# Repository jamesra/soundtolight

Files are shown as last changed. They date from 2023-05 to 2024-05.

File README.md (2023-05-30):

# Sound To Light

## Introduction

Sound to Light (aka Sound Delight) is a audio spectrogram display for Adafruit Feathers.  Among other uses it is a fun visual accompaniment to music.  

## Project Materials

### Hardware

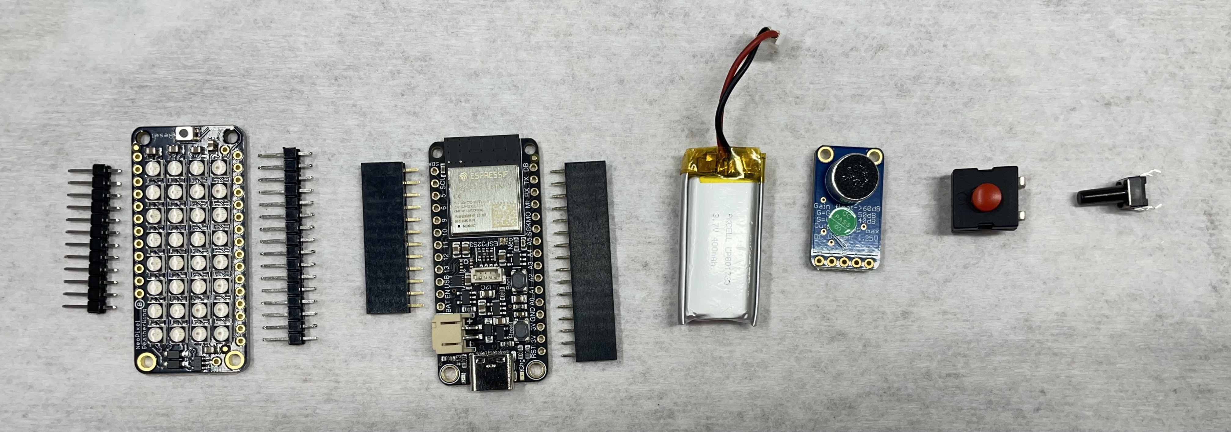
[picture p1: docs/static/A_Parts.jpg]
Parts


Displayed from left to right in the image above

- [Male Headers](https://www.adafruit.com/product/2886)
- [NeoPixel FeatherWing](https://www.adafruit.com/product/2945)
- [Female Headers](https://www.adafruit.com/product/2940)
- [ESP32-S3 board with 2MB PSRAM](https://www.adafruit.com/product/5477).
- *Optional* [Battery](https://www.adafruit.com/product/3898)
- [Electret Microphone with Auto Gain Control](https://www.adafruit.com/product/1713)
- 0.5m of any workable gauge [wire](https://www.adafruit.com/product/2515)
- *Optional* [On/Off Switch](https://www.adafruit.com/product/1683)
- *Optional* [Mode Button](https://www.adafruit.com/product/1490)

The case is 3D printed.  If you do not own a 3D printer many towns have a local 3D printing business.  If not there are online services that will mail a print.

### Tools:
    
- Soldering Iron
- Wire strippers

### Helpful Tools:

- Helping Hands
- Breadboard
- Flush Cutters
- Board Holder

## Instructions

### 1. Solder on the male headers onto the NeoPixel Featherwing display.  

The easiest way is insert the male headers into the breadboard with the long pins down so the featherwing can rest on top. 

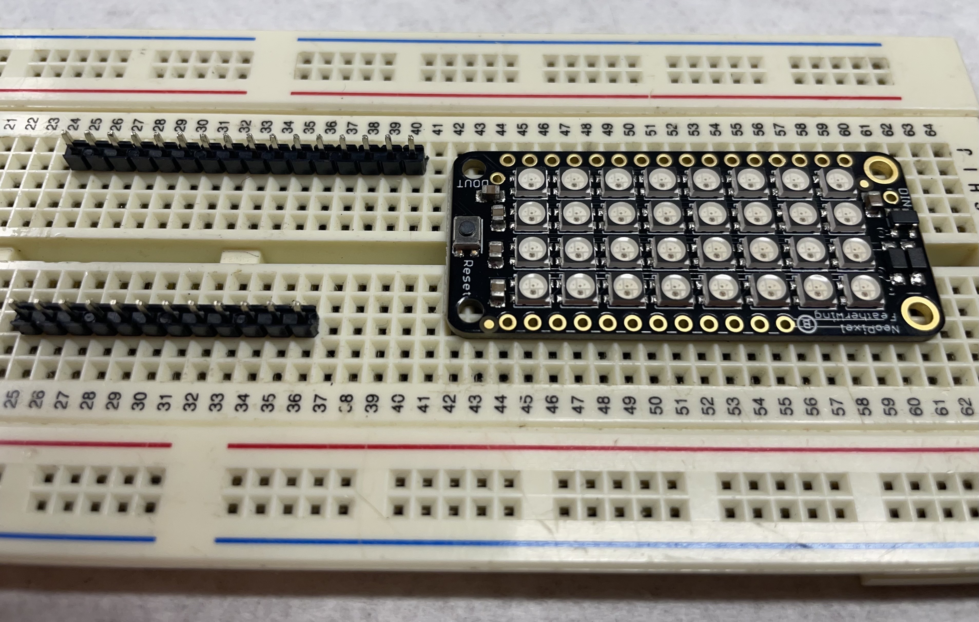
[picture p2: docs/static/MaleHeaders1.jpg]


Place the featherwing on top of the male headers. 

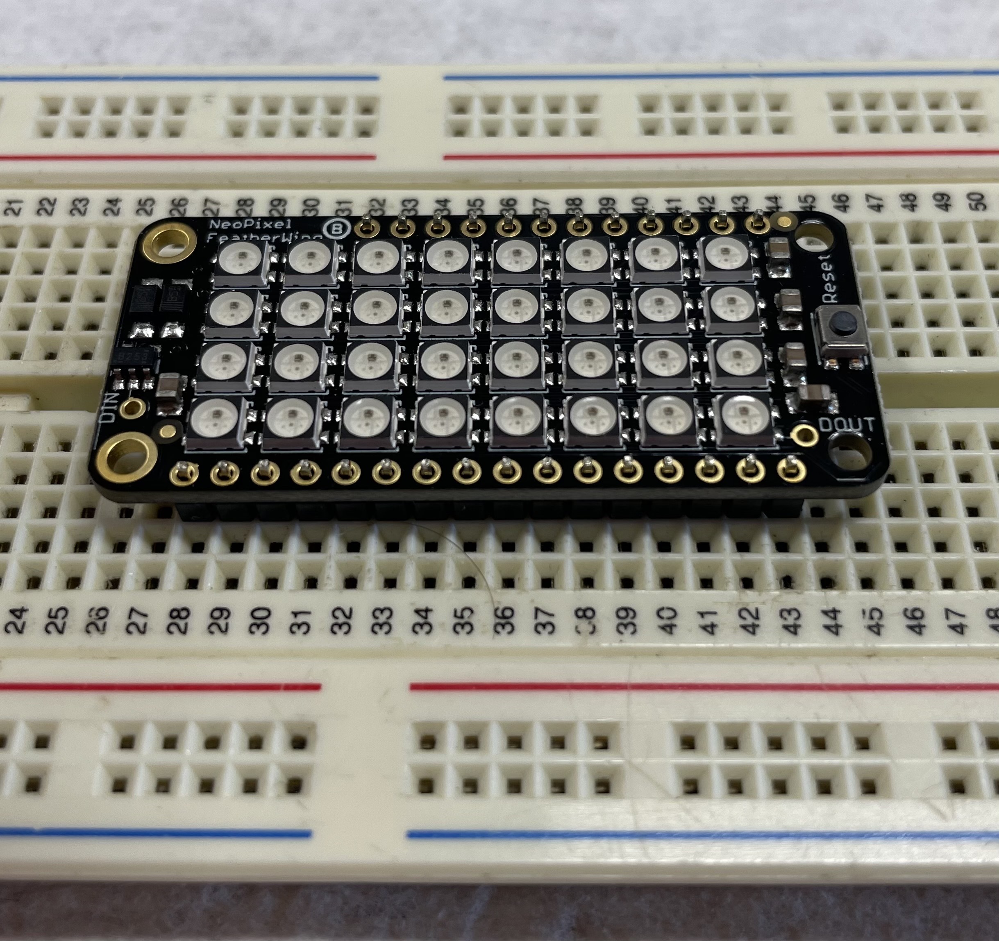
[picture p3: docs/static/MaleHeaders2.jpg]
 

*Note: If you do not have a breadboard, complete soldering the female headers to the ESP32-S3 from the step below, then place your male headers in the female headers to get the correct placement*

Solder each pin.  **Be very careful to not touch the NeoPixels with the iron as LEDs are sensitive to heat**  Seek help from an instructor or YouTube if you are new to soldering.  In general position the soldering iron to make full contact with the pin and try to limit contact with the pin to 2 to 3 seconds.  

### 2. Prepare the ESP32-S3 feather for wiring and soldering

If you had a breadboard, you can insert the female headers onto the neopixel headers, then rest the ESP32-S3 on top

If you did not have a breadboard, I recommend taping the female headers to the feather.  **Ensure the bottom of the board is being soldered.**

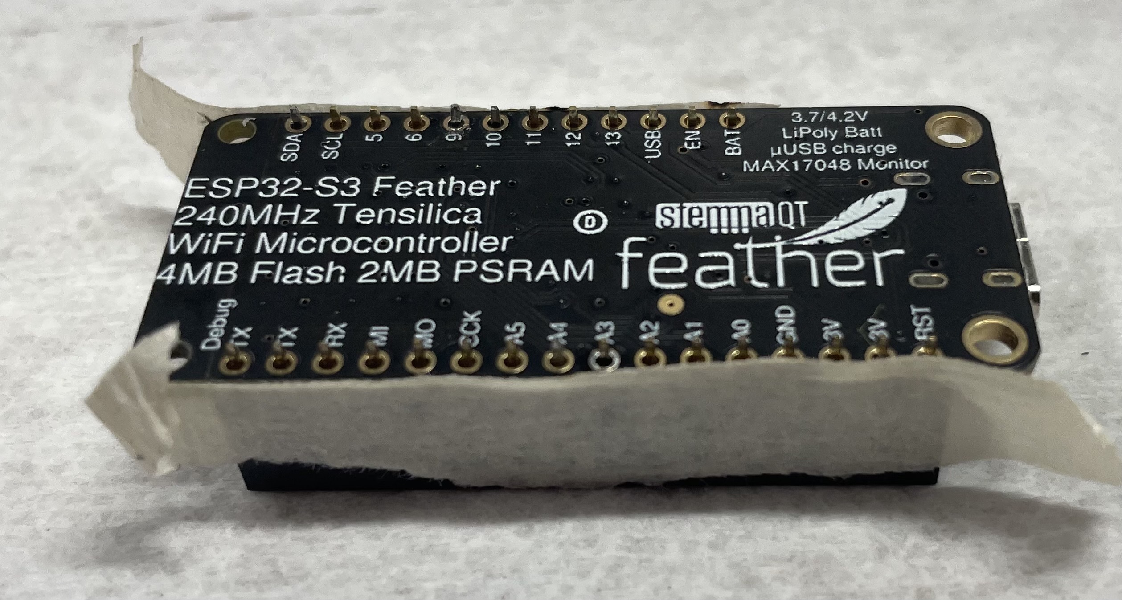
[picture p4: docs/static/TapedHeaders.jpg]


**Before soldering**, we need to add wires to the microphone.  The following pins need to be connected:

Microphone Wires (*Colors are only suggestions*)

- 3.3v (Red)   
- Ground (Green)
- A1 Input (Yellow) 
- A2 Gain (Orange)

Mode Button Wires (Optional)
- 3.3v (Red)
- D1 (Orange)
    
Strip about 1.5 to 2mm of wire using wire strippers: 

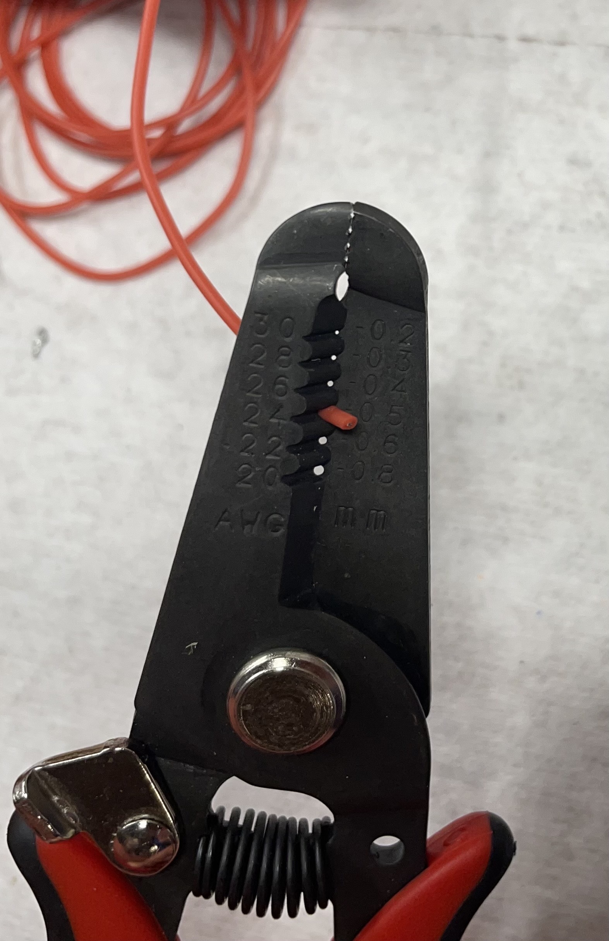
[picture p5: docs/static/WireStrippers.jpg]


Position the wire in the same hole as the header pin.  I sometimes find I can get the outer wire jacket over the header pin to help hold it in position

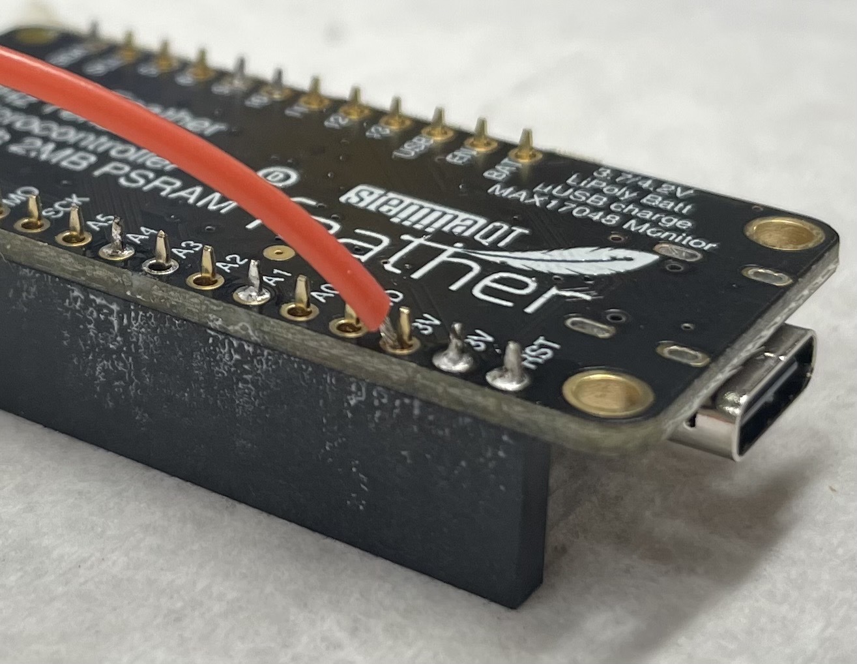
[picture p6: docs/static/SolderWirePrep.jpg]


If you are adding a mode button and want two wires on the 3.3v pin, I suggest twisting the stripped ends of two wires together, pushing that into the hole, and check carefully that no strands frayed out to touch adjacent pins.

Solder the wire and pin into position on the board.

### Solder the microphone

This is easiest with helping hands. 

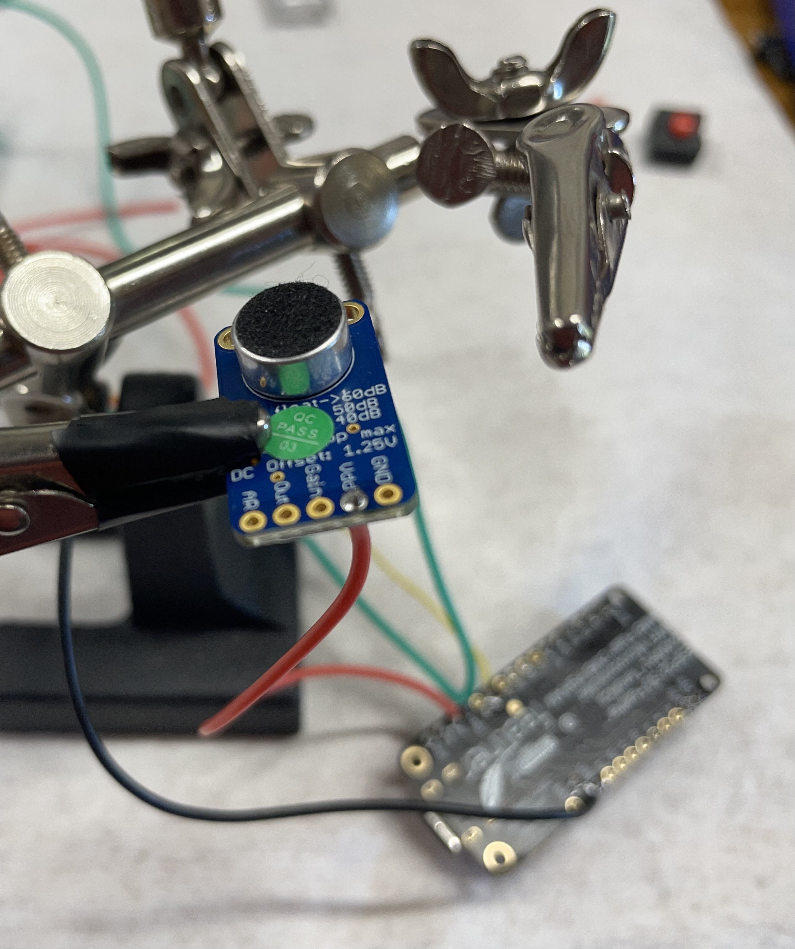
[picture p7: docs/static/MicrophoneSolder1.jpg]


This is the map for which wires to connect where

| ESP32-S3 | Microphone |
|---| --- |
| GND | GND |
| 3V | Vdd |
| A1 | Out |
| A2 | Gain |

*Upgrade option: Recording accuracy may be improved by adding a 100nf capacitor between the GND and Vdd inputs, particularly if you are not using battery power.  The capacitor can smooth any high frequency noise in the power supply.*

### Assemble the unit

If you are using the battery place it between the female headers on the ESP32-S3.  Place the Neopixel featherwing on top of the ESP32-S3 + Battery.  Push them gently together until the pins are fully seated.

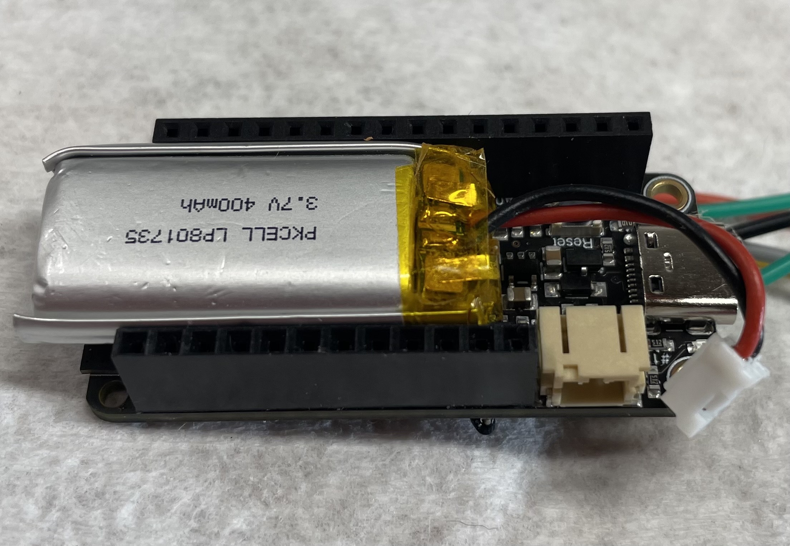
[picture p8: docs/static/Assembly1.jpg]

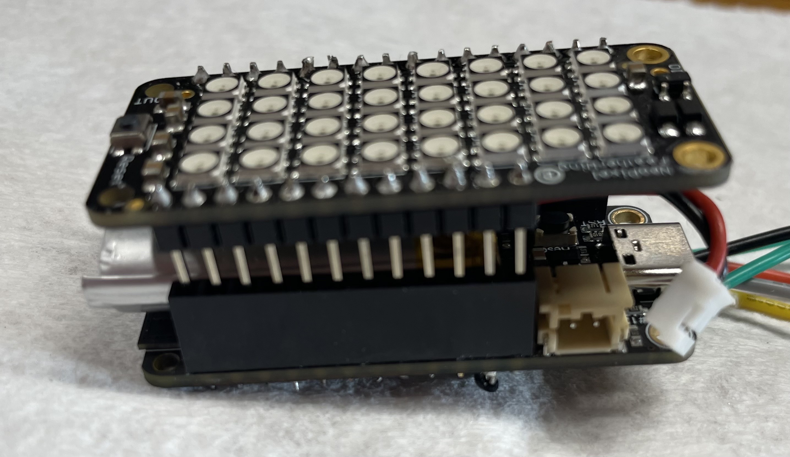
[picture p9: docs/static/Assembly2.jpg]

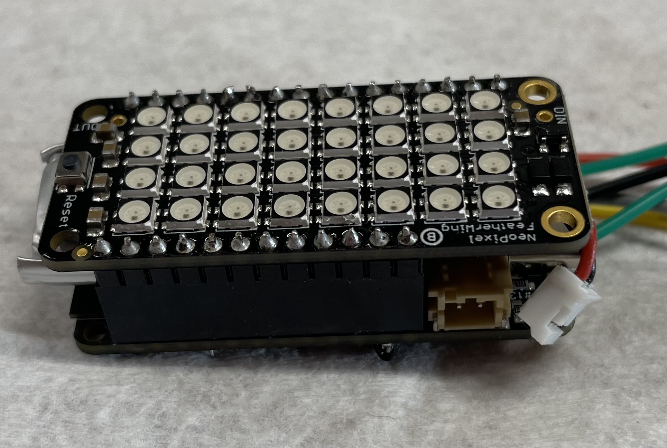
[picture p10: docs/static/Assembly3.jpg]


### Install the code

[Install CircuitPython 8.1 or above on the ESP32-S3](https://learn.adafruit.com/adafruit-esp32-s3-feather/circuitpython).

Download or clone the [sourcetolight project](https://github.com/jamesra/soundtolight) project.  Copy the contents of the [src](src) folder onto the CIRCUITPY drive.  (The .py files in the src folder should be on the root of the CIRCUITPY drive.)

If you have a python install on your computer open a command prompt.  Change to the CIRCUITPY drive (or the directory you cloned the source code to) and install the libraries to the ESP32-S3 

    pip install circup
    pip install -r requirements.txt

Otherwise you'll need to [manually download the python library bundle](https://circuitpython.org/libraries) and copy over the libraries listed in the [requirements.txt](requirements.txt) file.

### Turn on the power!

Either plug in the battery or connect the USB port.  The display should initialize and start displaying spectrograms!

## Optional Upgrades
 
If everything is working and you want to make it 'better' check out some [upgrade ideas](docs/upgrade_ideas.md).

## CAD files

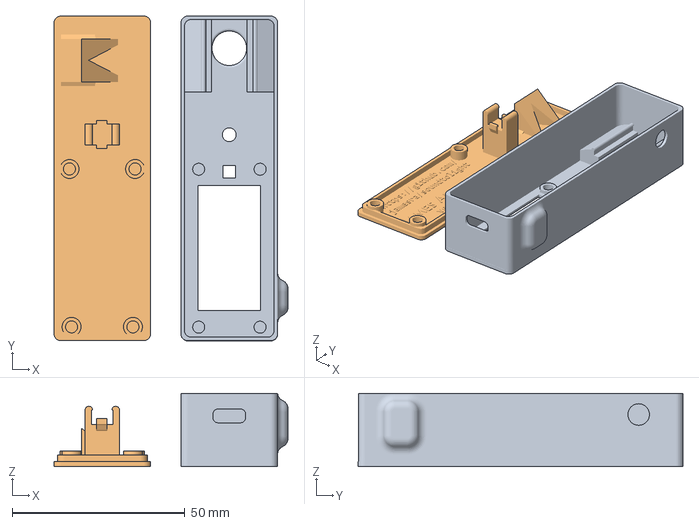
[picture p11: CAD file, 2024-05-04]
Sound-to-Light Case.3mf
67.7 x 94.1 x 21.1 mm
Lid Walls
Baseplate

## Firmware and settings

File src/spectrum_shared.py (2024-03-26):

try:
    import ulab.numpy as np
except ModuleNotFoundError:
    import numpy as np

import math


default_range_cutoffs = (0.03, 0.2, 0.4, 0.6, .8, 1.0)


def clip(value: float, min_val: float = 0, max_val: float = 1.0) -> float:
    '''
    Returns the value, or min/max if value falls outside the provided range
    :param value:
    :param min_val:
    :param max_val:
    :return:
    '''
    if value < min_val:
        return min_val
    if value > max_val:
        return max_val
    return value

def log_range(num_measurements: int, num_groups: int, base: float = None):
    '''Given a number of measurements and the desired grouping,
    returns the cutoff values to create bins evenly spaced in logarithmic space.
    '''
    log_range = math.log(num_measurements) if base is None else math.log(num_measurements, base)
    log_bin_spacing = log_range / num_groups
    log_bin_cutoffs = np.arange(0, num_groups+1)
    log_bin_cutoffs = log_bin_cutoffs * log_bin_spacing
    log_bin_cutoffs = np.exp(log_bin_cutoffs) if base is None else log_bin_cutoffs ** base
    return log_bin_cutoffs

def linear_range(num_measurements: int, num_groups: int):
    '''Given a number of measurements and the desired grouping,
    returns the cutoff values to create bins evenly spaced in normal space.
    '''
    bin_spacing = num_measurements / num_groups
    bin_cutoffs = np.arange(0, num_groups+1) * bin_spacing
    bin_cutoffs[0] = 1  #Remove the first group, it isn't interesting
    #print(f"{bin_cutoffs[0:3]} {bin_cutoffs[-1]} len: {len(bin_cutoffs)}" )
    if num_groups + 1 != len(bin_cutoffs):
        raise ValueError("num_groups and len(bin_cutoffs) must match")
    return bin_cutoffs


def float_to_indicies(input: np.array):
    '''Convert a float array to an integer array that can be used for indexing
    '''
    input = np.around(input)  # Round cutoffs to nearest integer so we can use them as indicies
    return np.array(input, dtype=np.uint16)

def space_indicies(input: np.array):
    '''
    When there are duplicates in an index array, change the values so there are no duplicates
    :param input:
    :return:
    '''
    spaced_input = np.zeros(len(input), dtype=input.dtype)
    spaced_input[0] = input[0]
    for i in range(1, len(input)):
        if input[i] <= spaced_input[i - 1]:
            spaced_input[i] = spaced_input[i-1] + 1
        else:
            spaced_input[i] = input[i]

    return spaced_input

def get_freq_powers_by_range(spectrum: np.ndarray[float], range_cutoffs: np.ndarray[int], out: np.ndarray[float] | None = None):
    '''
    Using a pre-calculated set of indicies for each range return the summed power for each group
    :param spectrum:
    :param range_cutoffs:
    :param out:
    :return:
    '''
    num_groups = range_cutoffs.shape[0] - 1
    if out is None:
        out = np.zeros((num_groups))  # Create a place to store the sum'ed power of each frequency range
    elif len(out) != num_groups:
        raise ValueError("Output array has the wrong shape")

    for i in range(0, num_groups):
        out[i] = np.sum(spectrum[range_cutoffs[i]:range_cutoffs[i + 1]])

    return out


# default_range_cutoffs = [0.15, 0.35, 0.65, 0.85, 1.0]
# default_base_color = [(0, 0, 0), #Red, Green, Blue weights for each range
#               (1, 0, 0),
#               (0, 1, 0),
#               (0, 0, 1),
#               (1, 1, 1)]


def map_normalized_value_to_color(normalized_value: float, colormap_index: int, color_map: list[tuple[float]]):
    '''

    :param value: value to convert to an RGB tuple
    :param min: min possible value
    :param max: max possible value
    :param ranges: range cutoffs to assign a value to a colormap range
    :param color_map: a colormap that multiples the value, after normalizing it within its range, to a color
    :return: A tuple of three integers, mapping RGB, with 0 representing OFF and 255 representing fully ON
    '''
    if colormap_index is None:
        raise ValueError('colormap_index must not be None')

    if normalized_value is None:
        raise ValueError('normalized_value must not be None')

    #Return a tuple for the normalized value, multiply each entry in the tuple by the color map
    return (normalized_value * color_map[colormap_index][0],
           normalized_value * color_map[colormap_index][1],
           normalized_value * color_map[colormap_index][2])

    raise ValueError("Value outside of color map range")


def map_normalized_powers_to_range(values: float, range_deltas:  list[float] | None = None):

    #lookup_table = np.vstack((np.array(range(len(values))), values)
    for i in range(len(range_deltas)):
        lookup_table[:,1] -= range_deltas[i]
        for value in np.where(lookup_table[:,1] <= 0):
            print(f'value: {value}')

def map_normalized_power_to_range(value: float, range_cutoffs:  list[float] | None = None):
    # i = np.argmax(range_cutoffs > value)
    # min_val = 0 if i - 1 < 0 else range_cutoffs[i-1]
    # #print(f'{value} -> {range_cutoffs} -> {i}')
    # range_normalized_value = (value - min_val) / (range_cutoffs[i] - min_val)
    # #print(f'v: {value} i: {i} v: {value - min_val} r: {range_cutoffs[i] - min_val}')
    # return i, range_normalized_value
    #
    for i, cutoff in enumerate(range_cutoffs):
        if value > cutoff:
            continue

        # Normalize where this value lives in the range and represent it as a number between 0 and 1.
        # For example, if the range is 3 to 9, and the value is 6, the normalized_value is 0.5.
        min_val = 0 if i - 1 < 0 else range_cutoffs[i-1]
        range_normalized_value = (value - min_val) / (range_cutoffs[i] - min_val)
        #print(f'v: {value} i: {i} v: {value - min_val} r: {range_cutoffs[i] - min_val}')

        #Return a tuple for the normalized value, multiply each entry in the tuple by the color map
        return i, range_normalized_value

    raise ValueError("Value outside of color map range")

def map_power_to_range(value: float, min_val: float, max_val: float, range_cutoffs: list[float] | None = None):
    '''
    Given a power, map it into a specific range.
    :param value: value to convert to an RGB tuple
    :param min_val: min possible value
    :param max_val: max possible value
    :param ranges: range cutoffs to assign a value to a colormap range
    :return: A tuple containing the index of the range the pixel mapped into and the normalized value of the
    pixel within that range.  For example, if the range array was [0, 5, 10] and the value 7.5 is passed, the
    return value is (1, 0.5), indicating the value maps to the second entry in the range array and is halfway
    through that range.
    '''
    range_cutoffs = default_range_cutoffs if range_cutoffs is None else range_cutoffs
    range = max_val - min_val
    if range == 0:
        return 0, 0

    value = (value - min_val) / range
    return map_normalized_power_to_range(value, range_cutoffs)


def map_float_color_to_neopixel_color(input: tuple[float], scalar: float | None = None) -> tuple[int]:
    '''
    Convert a tuple of values from 0 to 1 to a tuple of bytes from 0 to 255.  The
    output of this function can be passed to a neopixel to set a color
    :param value: tuple of three float values
    :param scalar: Optional, if included scales (multiplies) the color by the specified amount
    :return:
    '''
    scalar = 1.0 if scalar is None else scalar

    c =    int(input[0] * 255.0 * scalar), \
           int(input[1] * 255.0 * scalar), \
           int(input[2] * 255.0 * scalar)

    #print(f'{input} * {scalar} * 255 = {c}')
    return c

if __name__ == '__main__':
    # freq = np.arange(0, 1000, 20)
    # print(f'num freq: {len(freq)}')
    # log_indicies = log_range(len(freq), 8, 2)
    # print(f'log indicies: {log_indicies}')
    # range_indicies = float_to_indicies(log_indicies)
    # print(f'range indicies: {range_indicies}')
    # si = space_indicies(range_indicies)
    # print(f'spaced indicies: {si}')

    freq = np.arange(0, 1000, 20)
    print(f'num freq: {len(freq)}')
    log_indicies = log_range(len(freq), 128)
    print(f'log indicies: {log_indicies}')
    range_indicies = float_to_indicies(log_indicies)
    print(f'range indicies: {range_indicies}')
    si = space_indicies(range_indicies)
    print(f'spaced indicies: {si}')

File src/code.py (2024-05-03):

# This is a sample Python script.
import time
import math

import asyncio
import board
import analogbufio
import array
import ulab.numpy as np
import neopixel
import digitalio
from collections import namedtuple

import ulab.utils
import ema
import display_diagnostic
from recording_settings import RecordingSettings
import recording
from sound_rec import record_sample_array, record_sample_numpy
from basic_display import BasicDisplay
from waterfall_display import WaterfallDisplay
from graph_display import GraphDisplay
from fade_display import FadeDisplay
from display_settings import DisplaySettings
from pixel_indexers import *

import adafruit_dotstar as dotstar
from colormap import ColorMap
import standard_colormaps

# Known display configurations.
display_configs = {
    "32x8 Waterfall": DisplaySettings(num_rows=32, num_cols=8,
                                      pixel_indexer=columns_are_rows_with_alternating_column_order_indexer,
                                      log_scale=False),
    "8x32 Graph": DisplaySettings(num_rows=8, num_cols=32,
                                  pixel_indexer=rows_are_columns_with_alternating_reversed_column_order_indexer,
                                  log_scale=False),
    "8x4 Neopixel Feather Graph": DisplaySettings(num_rows=4, num_cols=8, pixel_indexer=flip_column_order_indexer,
                                                  log_scale=True),
    "8x4 Neopixel Feather Waterfall": DisplaySettings(num_rows=4, num_cols=8, pixel_indexer=flip_column_order_indexer,
                                                      log_scale=True),
    "4x16 Graph": DisplaySettings(num_rows=8, num_cols=32,
                                  pixel_indexer=rows_are_columns_with_alternating_reversed_column_order_indexer,
                                  num_neo_rows=8, num_neo_cols=32,
                                  log_scale=True),
    "6x12 Dotstar Feather Graph": DisplaySettings(num_rows=6, num_cols=12, pixel_indexer=standard_indexer,
                                                  log_scale=True),
    "12x6 Dotstar Feather Waterfall": DisplaySettings(num_rows=12, num_cols=6, pixel_indexer=rows_are_columns_indexer,
                                                      log_scale=True),
    "6x12 Dotstar Feather Waterfall": DisplaySettings(num_rows=6, num_cols=12, pixel_indexer=standard_indexer,
                                                      log_scale=True),
}

# The Electet Microphone used in this project can only sample at up to 20Khz according to its specs.  Higher values just add noise.
sampling_settings = {
    "Low Frequency": RecordingSettings(sampling_freq_hz=20000, frequency_cutoff=255, sample_size_exp=10),
    "Low-Mid Frequency": RecordingSettings(sampling_freq_hz=20000, frequency_cutoff=500, sample_size_exp=10),
    "Mids": RecordingSettings(sampling_freq_hz=20000, frequency_cutoff=4000, sample_size_exp=10),
    "High-Mids": RecordingSettings(sampling_freq_hz=20000, frequency_cutoff=6000, sample_size_exp=10),
    "Highs": RecordingSettings(sampling_freq_hz=20000, frequency_cutoff=10000, sample_size_exp=10),
}

sample_settings = sampling_settings["Mids"]

MIC_PIN = board.A5

purple_colormap = ColorMap(standard_colormaps.purple_colors, standard_colormaps.default_graph_cutoffs)
purple_basic_colormap = ColorMap(standard_colormaps.purple_colors, standard_colormaps.default_basic_cutoffs)
green_colormap = ColorMap(standard_colormaps.green_colors, standard_colormaps.default_graph_cutoffs)
red_colormap = ColorMap(standard_colormaps.red_colors, standard_colormaps.default_graph_cutoffs)
rainbow_colormap = ColorMap(standard_colormaps.default_colors, standard_colormaps.default_graph_cutoffs)
rainbow_basic_colormap = ColorMap(standard_colormaps.default_colors, standard_colormaps.default_basic_cutoffs)



class NeoPixelFeatherWing:
    @property
    def display_modes(self):
        return self._display_modes

    def __init__(self):
        NeoPixelFeatherWing._pixels = neopixel.NeoPixel(board.D6, n=4 * 8, brightness=0.05, auto_write=False)
        self._display_modes = (
            GraphDisplay(NeoPixelFeatherWing._pixels, display_configs["8x4 Neopixel Feather Graph"],
                         cmap=green_colormap),
            WaterfallDisplay(NeoPixelFeatherWing._pixels, display_configs["8x4 Neopixel Feather Waterfall"]),
            FadeDisplay(NeoPixelFeatherWing._pixels, display_configs["8x4 Neopixel Feather Graph"],
                        cmap=purple_colormap, smooth_factor=2.66, smooth_samples=3),
            BasicDisplay(NeoPixelFeatherWing._pixels, display_configs["8x4 Neopixel Feather Graph"],
                         cmap=rainbow_colormap),
        )


class NeoPixel32x8Matrix:
    @property
    def display_modes(self):
        return self._display_modes

    def __init__(self):
        NeoPixel32x8Matrix._pixels = neopixel.NeoPixel(board.D10, n=8 * 32, brightness=0.05, auto_write=False)
        self._display_modes = (
            GraphDisplay(NeoPixel32x8Matrix._pixels, display_configs["8x32 Graph"], cmap=green_colormap),
            WaterfallDisplay(NeoPixel32x8Matrix._pixels, display_configs["32x8 Waterfall"]),
            FadeDisplay(NeoPixel32x8Matrix._pixels, display_configs["8x32 Graph"], cmap=purple_colormap,
                        smooth_factor=2.66,
                        smooth_samples=3),
        )


class DotStarFeatherWing:
    @property
    def display_modes(self):
        return self._display_modes

    def __init__(self):
        DotStarFeatherWing._dotstar = dotstar.DotStar(board.D13, board.D11, 12 * 6, brightness=.1, auto_write=False)
        self._display_modes = (
            GraphDisplay(DotStarFeatherWing._dotstar, display_configs["6x12 Dotstar Feather Graph"],
                         cmap=green_colormap),
            FadeDisplay(DotStarFeatherWing._dotstar, display_configs["6x12 Dotstar Feather Graph"],
                        cmap=red_colormap,
                        smooth_factor=2.5, smooth_samples=4),
            WaterfallDisplay(DotStarFeatherWing._dotstar, display_configs["12x6 Dotstar Feather Waterfall"]),
            WaterfallDisplay(DotStarFeatherWing._dotstar, display_configs["6x12 Dotstar Feather Waterfall"]),
            WaterfallDisplay(DotStarFeatherWing._dotstar, display_configs["6x12 Dotstar Feather Waterfall"], cmap=green_colormap),
            BasicDisplay(DotStarFeatherWing._dotstar, display_configs["6x12 Dotstar Feather Graph"],
                         cmap=rainbow_colormap),
            BasicDisplay(DotStarFeatherWing._dotstar, display_configs["6x12 Dotstar Feather Graph"],
                         cmap=purple_basic_colormap),
        )


# On-board DotStar for boards including Gemma, Trinket, and ItsyBitsy
display = DotStarFeatherWing()
#display = NeoPixelFeatherWing()
# display = NeoPixel32x8Matrix()
display_modes = display.display_modes
iDisplayMode = 0
display_mode = display_modes[iDisplayMode]
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

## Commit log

2023-05-29 Experimental filtering to prevent ringing artifacts
    [basic_display.py, code.py, graph_display.py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]
2023-05-30 A bit more cleanup before calling it a day Fixed flipped 'hanning' vs 'hamming' filter
    [code.py, display_diagnostic.py, display_settings.py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]
2023-05-30 Fixed filter named. Minor cleanup
2023-05-31 Use a better hanning filter Remove extra cruft
2023-06-03 Added dotstar support Refactored Display range to a new class Added random sample generator Added an indexer
2023-06-18 Optimizations Got Basic display working again Added a button to switch through display types A few refactorings. Still work to do.
2024-03-26 First workable case, pain to assemble still
    [Sound-to-Light Case.3mf]
2024-03-26 Trying a different strategy for adapting the magnitude of each frequency in the display. Using a power function to focus on the most dominant frequencies.
2024-05-04 Adding a decent case, designed to work with the dotstar 6x12 feather.
    [Sound-to-Light Case.3mf]
